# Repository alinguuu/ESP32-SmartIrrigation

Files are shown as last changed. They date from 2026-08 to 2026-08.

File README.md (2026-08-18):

# 🌿 Industrial ESP32 Smart Irrigation & Climate Automation Platform

An industrial-grade, fully integrated smart irrigation and climate automation ecosystem powered by the ESP32. Designed for real-world agricultural, greenhouse, and field applications, this platform unites multi-zone solenoid valve control, digital environmental telemetry, custom 3D CAD/STL hardware enclosures, addressable visual status indicators, and TOTP 2FA security into a unified IoT solution.

<details>
  <summary>🔍 Click to View Full Hardware Wiring Diagram</summary>
  <br>
  <p align="center">
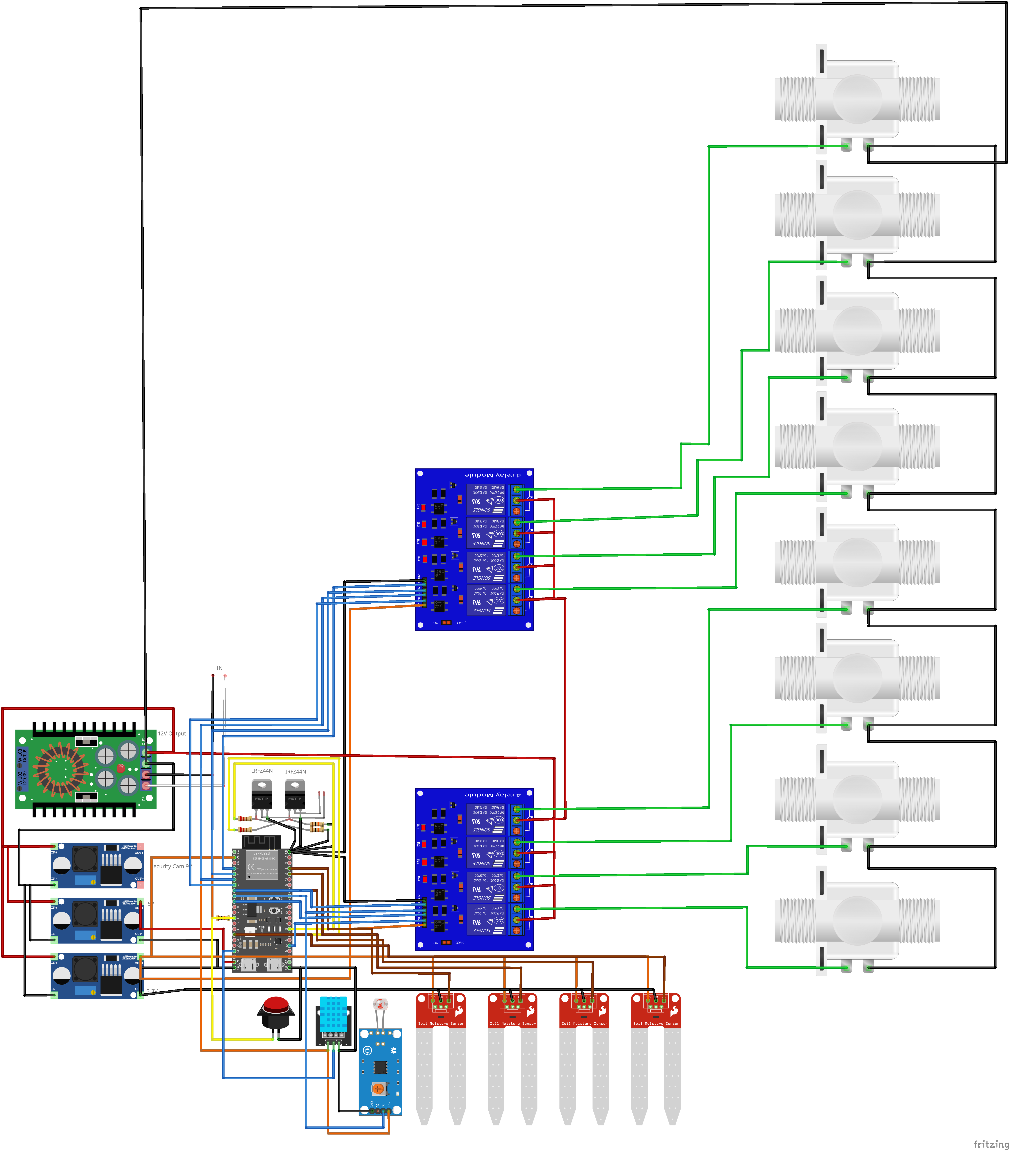
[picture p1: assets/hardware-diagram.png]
Hardware Wiring Diagram
    
  </p>
</details>

---

## 🚀 Overview & System Architecture

Unlike typical hobbyist IoT projects that rely on generic breadboards or basic relay modules, this platform is engineered from the ground up for industrial field reliability, high physical durability, and multi-layered security.

It bridges the gap between low-level hardware control and high-level user accessibility by providing both a responsive Web Control Panel for desktop browsers and a standalone Android application for field operation.

---

## 🌟 Key Features & Capabilities

### 💧 Multi-Zone Solenoid Valve Control
* **8 Independent Relay Channels:** Capable of driving 8 high-power 12V/24V solenoid valves across different irrigation zones (e.g., greenhouses, drip lines, flower beds).
* **Automatic Safety Cutoff Timers:** Features an integrated 30-minute safety timer per relay channel to prevent accidental field flooding or crop damage in the event of network disconnection.

### 📊 Digital Telemetry & Environmental Sensing
* **4-Zone Digital Soil Moisture Monitoring:** Reads digital high/low soil saturation levels to automate watering routines dynamically.
* **Climate Monitoring:** Integrated DHT11 sensor tracks ambient temperature and humidity in real time.
* **Light Intensity Sensing:** Onboard LDR sensor detects sunlight exposure to optimize night/day irrigation scheduling.

### 🔒 Industrial Security (TOTP 2FA)
* **Time-based One-Time Password (2FA):** Implements a Time-based One-Time Password (TOTP) algorithm directly on the ESP32. Sensitive manual overrides, valve toggles, and system settings require valid 2FA authentication via standard mobile authenticator apps (Google Authenticator, Authy).

### 💡 Visual Status Feedback (WLED & Indicators)
* **Addressable WLED Status Lighting:** Utilizes addressable LED strips to provide instant visual diagnostic codes across the enclosure (e.g., active zone indicators, error alerts, standby breathing effects).
* **Enclosure & Panel Lighting:** Auxiliary MOSFET output drivers support high-brightness enclosure LEDs and physical panel status indicators.

---

## 🎨 Custom 3D CAD & Hardware Enclosure Suite

The platform features a complete custom-designed 3D CAD ecosystem stored in the `assets/` directory. All models are optimized for 3D printing (PLA/PETG/TPU) and field deployment:

* **Banana Pi Pro A20 SBC Housing:** Features a hexagonal airflow pattern with active fan mounting to house the central server unit (`cad-bananapi-case-bottom-hex.stl`, `cad-bananapi-case-top-fan.stl`).
* **Soil Sensor Protective Casings:** Weatherproof vertical enclosures with protective top caps designed to shield sensitive electronics from outdoor dirt and moisture (`cad-soil-sensor-casing.stl`, `cad-soil-sensor-cap.stl`).
* **Solenoid Valve Enclosures:** Custom manifold covers equipped with cutouts for status LEDs (`cad-valve-enclosure-main.stl`, `cad-valve-top-cover-led.stl`).
* **Modular Cable Management Boxes:** Junction boxes built for green pluggable terminal blocks to ensure clean wiring and prevent short circuits (`cad-cable-junction-box-large.stl`, `cad-cable-junction-box-small.stl`).
* **Main Panel Chassis:** Heavy-duty internal chassis plate for organized electrical cabinet mounting (`cad-main-mounting-plate.stl`).

---

## 🖥️ User Interfaces & Remote Control

* **Responsive Web Dashboard:** Access real-time sensor graphs, set automated timers, view system logs, and manually trigger valve channels from any desktop or mobile browser.
* **Native Android Application:** Pre-compiled Android APK for quick field control without needing to open a browser.
* **Physical Panel Control:** Includes manual physical button inputs directly on the enclosure for local field operations.

---

## 🛠️ Complete Hardware Wiring & Fritzing Schematic

The hardware layout integrates power regulation, logic isolation, and sensor buses into a clean industrial enclosure:

* **Editable Fritzing Source:** Available at [`assets/hardware-diagram.fzz`](assets/hardware-diagram.fzz).
* **High-Resolution Diagram:** Available at [`assets/hardware-diagram.png`](assets/hardware-diagram.png).

---

## 📖 Complete Technical Setup Guide

For detailed hardware pin mappings, step-by-step firmware compiling, library dependencies, software flashing, and Android APK installation instructions, please refer to our dedicated guide:

➡️ **[View Full Technical Setup & Installation Guide (SETUP.md)](SETUP.md)**

---

> 🇹🇷 **Türkçe Makale & Detaylı İnceleme**  
> Bu projenin Türkçe kurulum rehberine, donanım mimarisine ve saha tecrübelerine [utkudsoz.com.tr](https://utkudsoz.com.tr/esp32-s3-ile-endustriyel-akilli-sulama-ve-iklim-otomasyonu/) üzerinden ulaşabilirsiniz.

---

## 📄 License

Distributed under the MIT License. See `LICENSE` for more information.

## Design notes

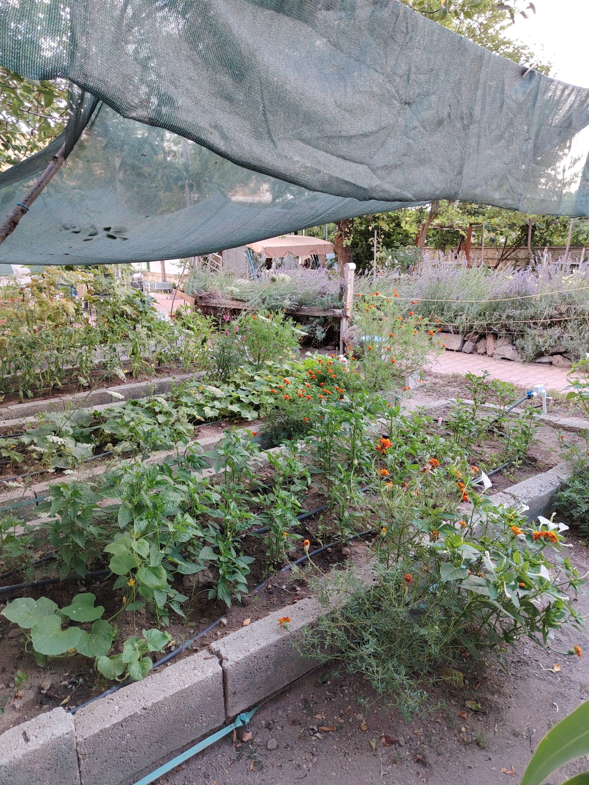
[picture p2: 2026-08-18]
assets/photo-gallery/field-garden-overview.jpeg

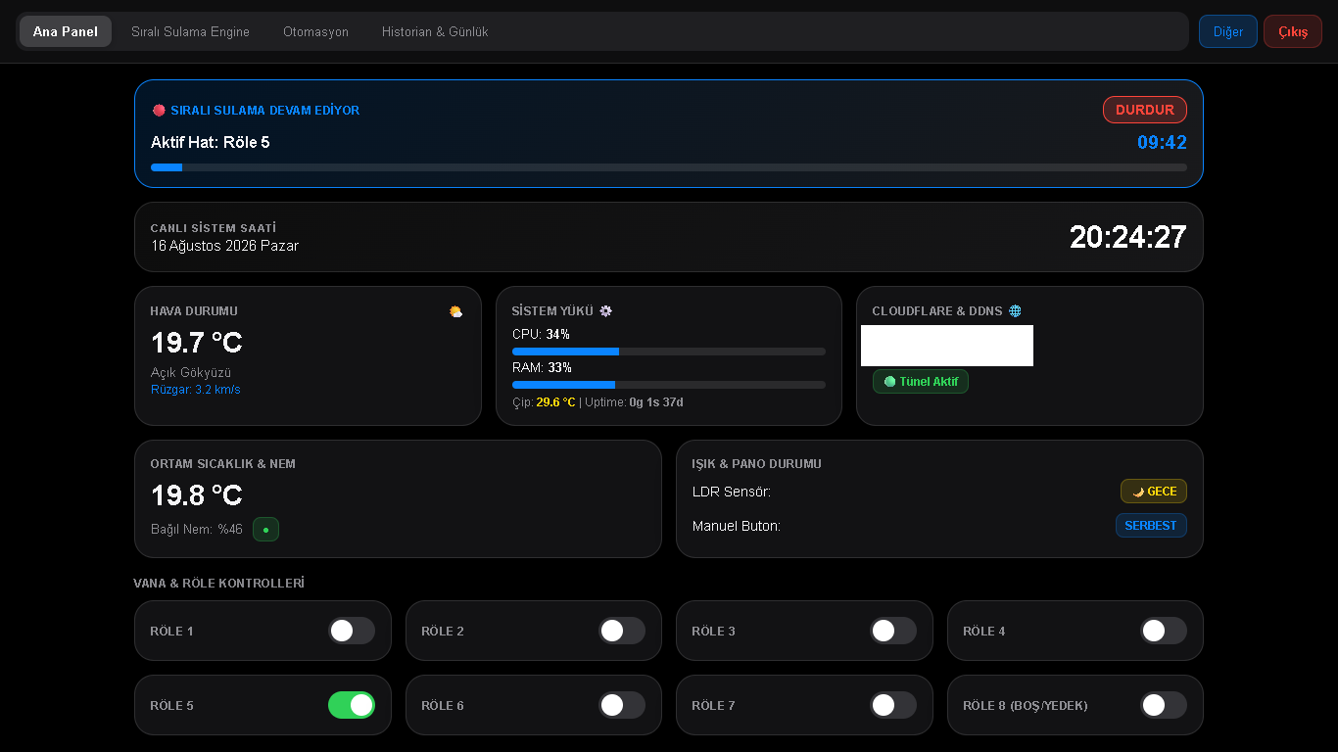
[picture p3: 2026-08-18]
assets/photo-gallery/ui-dashboard-overview.png

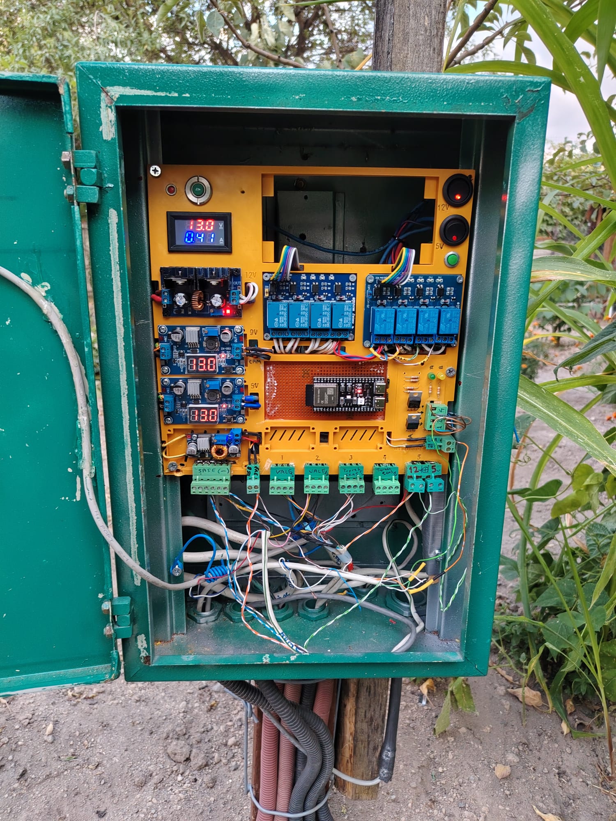
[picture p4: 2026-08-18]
assets/photo-gallery/box-overview.jpeg

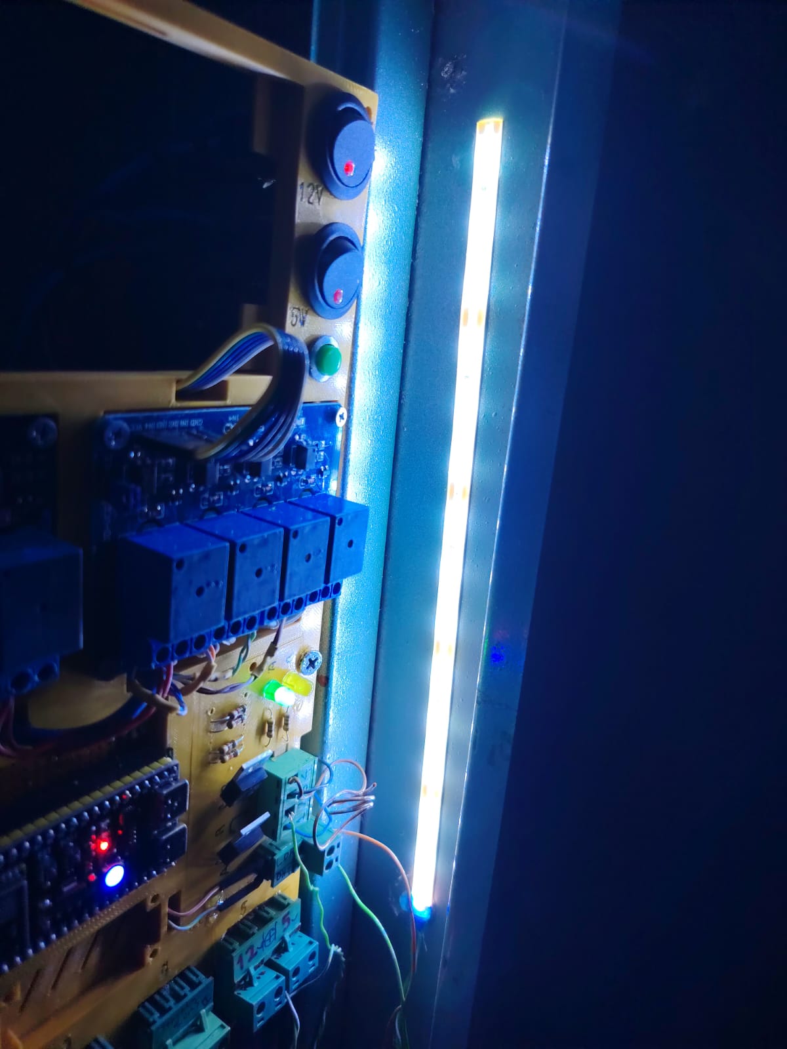
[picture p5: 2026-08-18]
assets/photo-gallery/box-inside-LED.jpeg

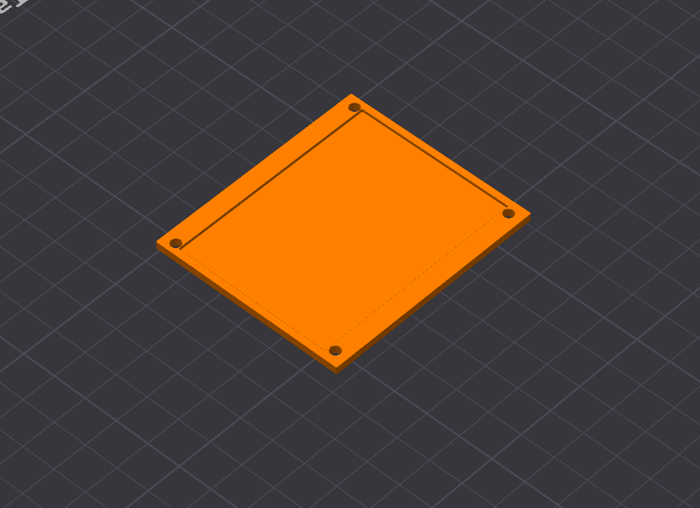
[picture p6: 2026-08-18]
assets/3d-files/cable-box-cover-large.png

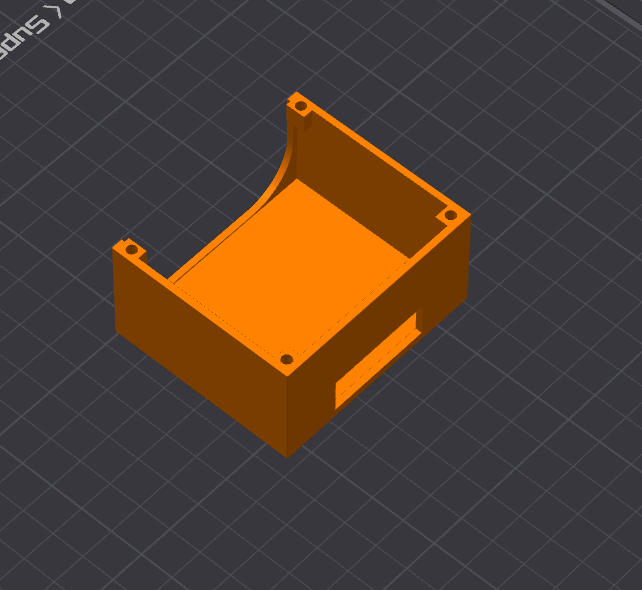
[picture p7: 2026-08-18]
assets/3d-files/cable-junction-box-large.png

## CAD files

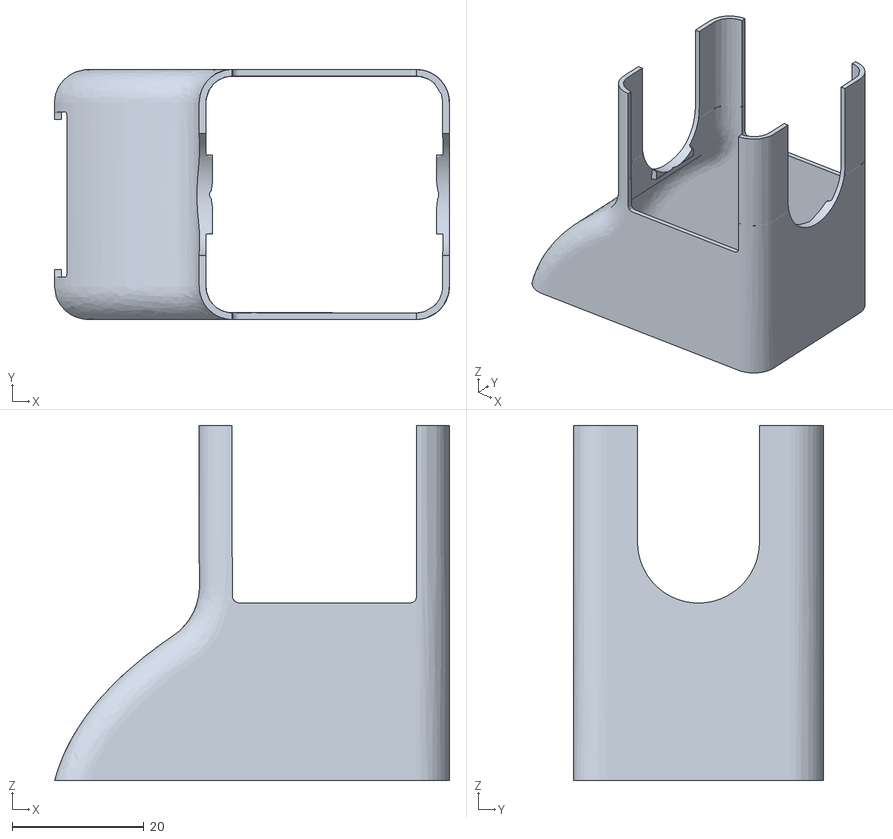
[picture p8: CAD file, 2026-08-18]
assets/3d-files/valve-enclosure-main.stl
60.0 x 38.0 x 54.0

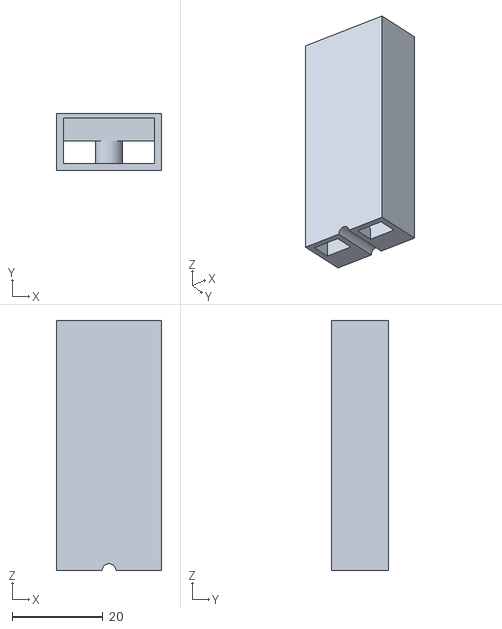
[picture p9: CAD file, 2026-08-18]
assets/3d-files/soil-sensor-casing.stl
23.0 x 12.5 x 55.0

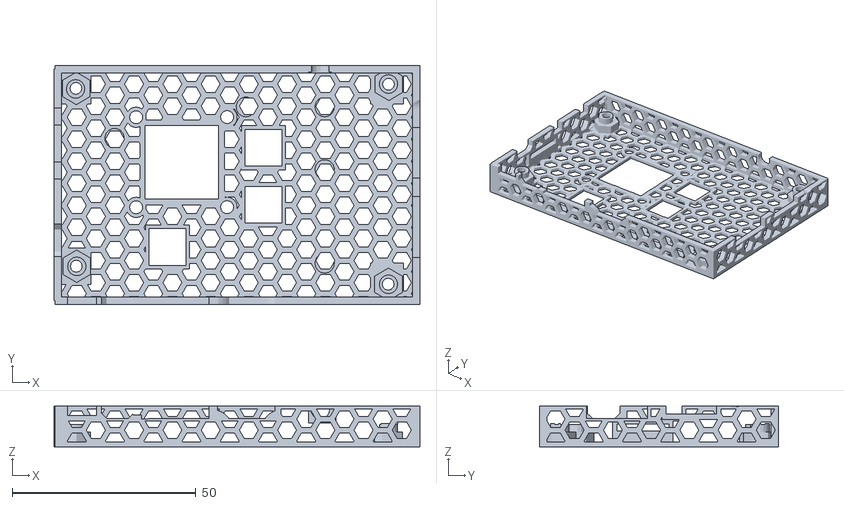
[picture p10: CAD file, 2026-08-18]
assets/3d-files/bananapi-case-bottom-fan.stl
99.6 x 65.1 x 11.0

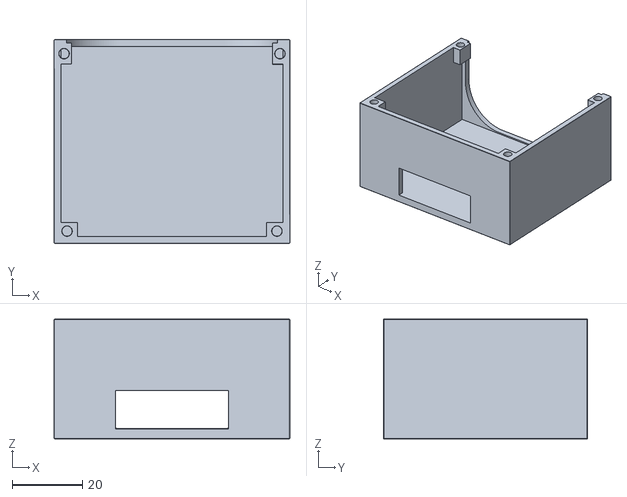
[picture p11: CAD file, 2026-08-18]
assets/3d-files/cable-junction-box-large.stl
67.0 x 58.0 x 34.0

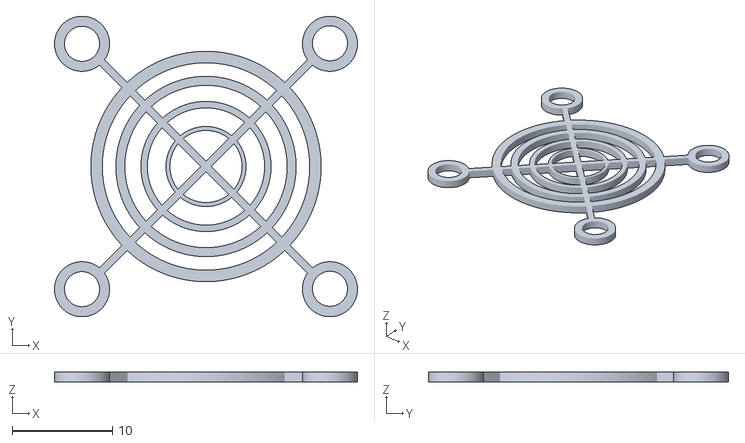
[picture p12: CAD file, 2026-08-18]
assets/3d-files/fan-grille.stl
30.2 x 30.0 x 1.00

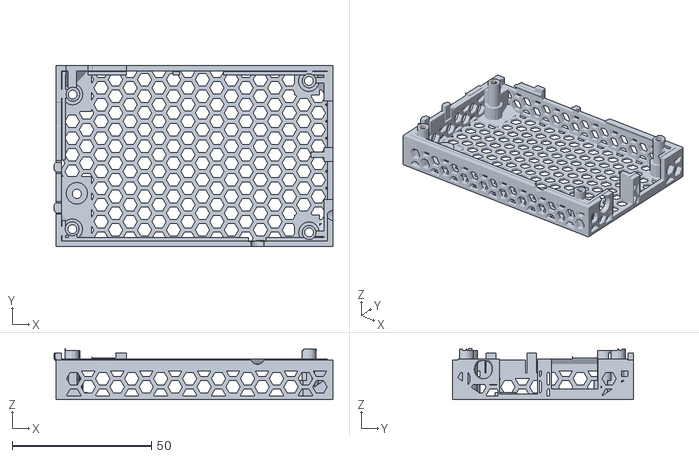
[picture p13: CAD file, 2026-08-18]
assets/3d-files/bananapi-case-top.stl
100.2 x 65.1 x 18.4

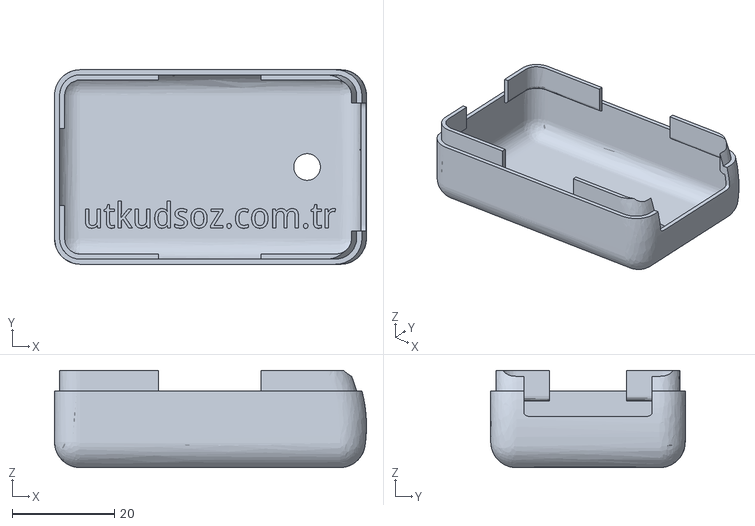
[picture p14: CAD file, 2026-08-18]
assets/3d-files/valve-top-cover-led.stl
60.9 x 38.0 x 19.0

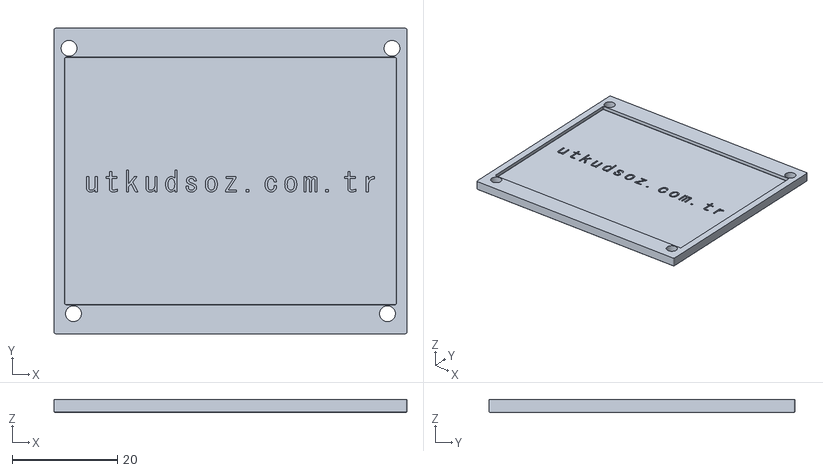
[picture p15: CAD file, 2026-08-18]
assets/3d-files/cable-box-cover-large.stl
67.0 x 58.0 x 2.49

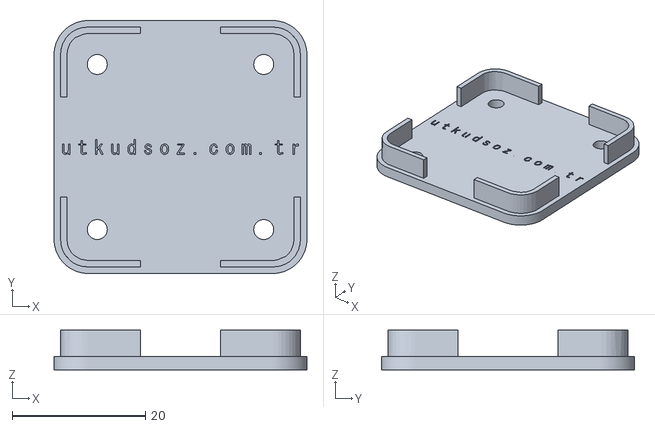
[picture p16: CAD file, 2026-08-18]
assets/3d-files/valve-mount-plate.stl
38.0 x 38.0 x 6.00

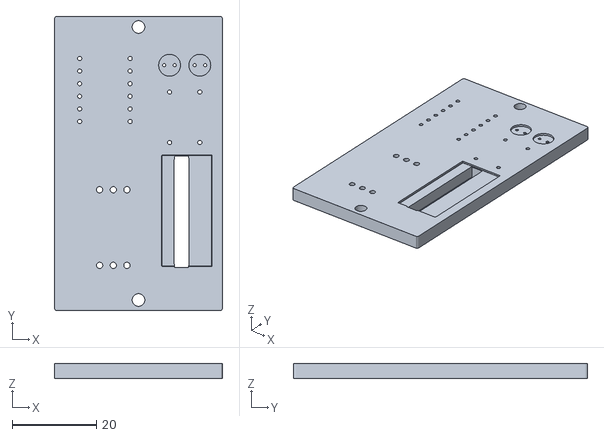
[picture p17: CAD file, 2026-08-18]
assets/3d-files/mosfet-driver-plate.stl
40.0 x 70.0 x 3.50

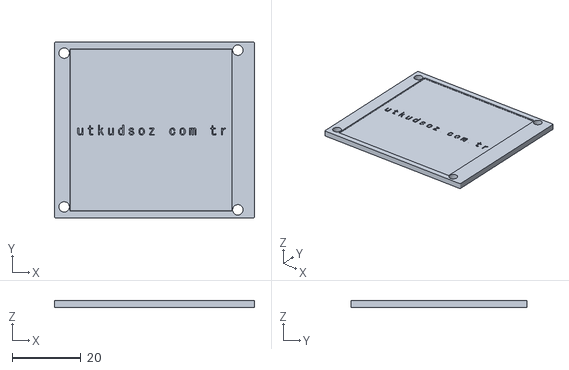
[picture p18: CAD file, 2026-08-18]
assets/3d-files/cable-box-cover-small.stl
58.0 x 51.0 x 2.00

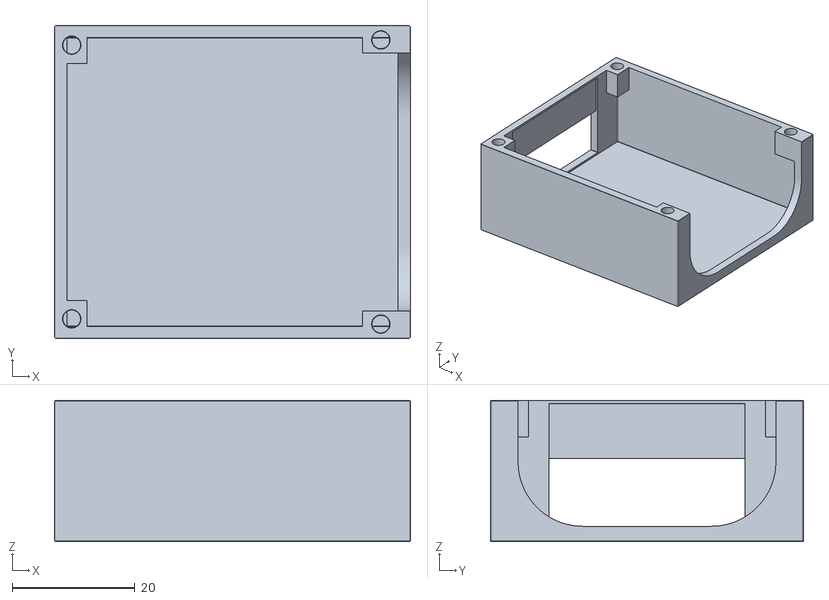
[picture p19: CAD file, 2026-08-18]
assets/3d-files/cable-junction-box-small.stl
58.0 x 51.0 x 23.0

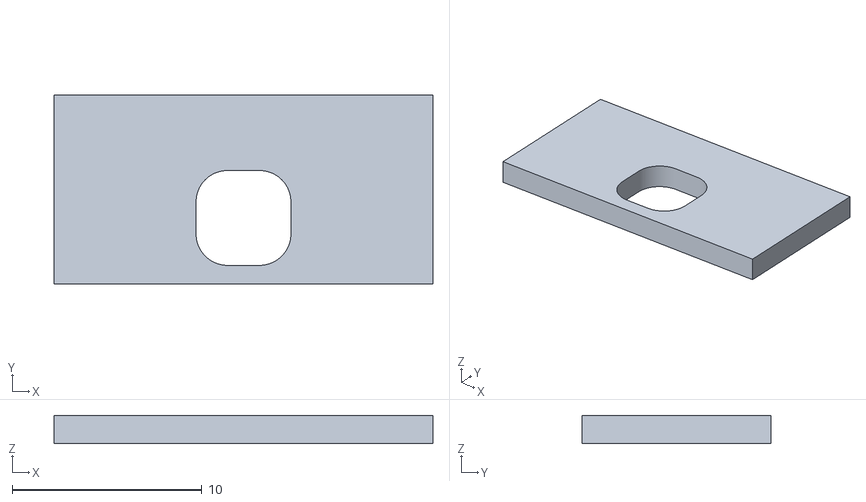
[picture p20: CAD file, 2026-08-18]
assets/3d-files/soil-sensor-cap.stl
20.0 x 10.0 x 1.50

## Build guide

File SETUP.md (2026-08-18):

# 🛠️ Complete Technical Setup & Deployment Guide

This is the comprehensive technical manual for setting up, compiling, configuring, and deploying the **ESP32-S3 Smart Irrigation & Climate Automation Platform**.

---

## 📐 Schematics & Source Links

* **Wiring Diagram:** [`assets/hardware-diagram.png`](https://github.com/alinguuu/ESP32-SmartIrrigation/blob/main/assets/hardware-diagram.png)
* **Fritzing Project:** [`assets/hardware-diagram.fzz`](https://github.com/alinguuu/ESP32-SmartIrrigation/blob/main/assets/hardware-diagram.fzz)
* **Main Firmware (`main.ino`):** [`main.ino`](https://github.com/alinguuu/ESP32-SmartIrrigation/blob/main/main.ino)
* **Web UI Header (`index.h`):** [`index.h`](https://github.com/alinguuu/ESP32-SmartIrrigation/blob/main/index.h)

---

## 📦 Bill of Materials (BOM)

### Controller & Computing
* **ESP32-S3-DevKitC-1-N8R2** (8MB Flash / 2MB PSRAM)
* **Banana Pi Pro A20** (Network server/broker, housed in a custom 3D case)

### Power Management
* **1x XL4016 Buck Converter:** Main 12V DC power rail for solenoid valves.
* **1x XL6009 Buck-Boost:** 9V DC output for auxiliary camera hardware.
* **1x XL6009 Buck-Boost:** 5V DC output for ESP32-S3 board and relay logic.
* **1x XL6009 Buck-Boost:** 3.3V DC output dedicated to sensor logic.

### Actuators & Sensors
* **2x 4-Channel Relay Modules** (8 solenoid valves, switching 12V DC)
* **2x IRFZ44N MOSFETs** (Enclosure LED and secondary high-power outputs)
* **4x Digital Soil Moisture Sensors**
* **1x DHT11 Sensor** (Temperature & Humidity)
* **1x LDR Light Sensor Module** (Digital Output via LM393)
* **1x Physical Panel Pushbutton**
* **1x WS2812B / WLED Strip** (Remote network-connected visual indicator)

---

## 🔌 Pin Mapping Summary

| Module / Function | Pin | ESP32-S3 GPIO | Signal Type |
| :--- | :--- | :--- | :--- |
| **Relay Channels (1-8)** | IN1 - IN8 | `GPIO 4, 5, 6, 7, 15, 16, 17, 21` | Digital Output (5V) |
| **Soil Sensors (1-4)** | DO | `GPIO 1, 2, 10, 40` | Digital Input (3.3V) |
| **DHT11 Sensor** | DATA | `GPIO 13` | Digital Input (3.3V) |
| **LDR Sensor** | DO | `GPIO 39` | Digital Input (3.3V) |
| **Panel Pushbutton** | STATE | `GPIO 3` | Digital Input (Pull-Up) |
| **Enclosure LED MOSFET**| GATE | `GPIO 45` | PWM Output |
| **Auxiliary MOSFET** | GATE | `GPIO 46` | PWM Output |

---

## 💻 Step-by-Step Firmware Setup & Flashing

### Step 1: Environment Preparation
1. Install **VS Code** with the **PlatformIO** extension (recommended) or **Arduino IDE 2.x**.
2. If using Arduino IDE, install the **ESP32 Board Package** via Board Manager (`https://raw.githubusercontent.com/espressif/arduino-esp32/gh-pages/package_esp32_index.json`).
3. Select board target: `ESP32S3 Dev Module`.

### Step 2: Library Dependencies
Ensure the following libraries are installed before compilation:
* `WiFi.h` & `WebServer.h` (ESP32 Core)
* `HTTPClient.h` (WLED API Requests)
* `DHT sensor library` by Adafruit
* `Preferences.h` & `LittleFS.h` (NVS Storage)
* `mbedtls/sha1.h` (Hardware TOTP Cryptography)

### Step 3: Understanding `index.h`
The entire web interface (HTML, CSS, JavaScript) is placed inside `index.h` using standard C++ `PROGMEM` syntax:
* **Memory Optimization:** Stored directly in ESP32-S3 Flash memory, keeping RAM free for real-time sensor cycles.
* **Modularity:** Keeps core logic in `main.ino` clean and separate from web design code.

### Step 4: Configuring Parameters & Flashing
1. Open `main.ino` and update Wi-Fi credentials (`ssid`, `password`).
2. Set your custom **TOTP Secret Key** (Base32 string).
3. Connect the ESP32-S3 via USB-C (ensure correct COM port selected).
4. Set partition scheme to **8MB with Spiffs/LittleFS** if prompted.
5. Click **Upload / Flash** and monitor output via Serial Monitor at **115200 baud**.

---

## 🔒 TOTP 2FA Setup

1. Locate the Base32 Secret Key defined in `main.ino`.
2. Open your 2FA app (**Google Authenticator**, **Authy**, or **1Password**).
3. Choose **"Enter a setup key"** / **"Manual entry"** and paste the key.
4. Name the entry (e.g., *Irrigation System*).
5. Any manual command sent via the Web UI or Mobile App will require the active 6-digit TOTP code generated by your app.

---

## 📲 Mobile App (APK) Setup & Domain Editing

The pre-compiled Android APK targets the default domain: `sulama.utkudsoz.com.tr`.

If you are using a self-hosted server or direct IP, update the APK using **APK Editor**:

1. Download **APK Editor** (Android) or **APK Easy Tool** (Windows).
2. Load the project's APK file.
3. Choose **Full Edit** / **Common Edit**.
4. Search for `sulama.utkudsoz.com.tr` in `assets/` or `res/values/strings.xml`.
5. Replace it with your custom IP or domain (e.g., `192.168.1.100`).
6. Click **Build**, sign the application with a test key, and install it on your smartphone.

---

## 🖨️ 3D Enclosure Assembly & Field Deployment

### Printing Guidelines
* **Material:** PETG or ASA (UV and weather resistant for outdoor environments).
* **Layer Height:** `0.2mm`or `0.12mm`| **Infill:** `20%-30% Gyroid`.

### Assembly Steps
1. **SBC Housing:** Mount Banana Pi Pro A20 in `bananapi-case-bottom-fan.stl` and secure a 5V fan on `bananapi-case-top.stl`.
2. **Soil Probe Protection:** Insert soil probes into `soil-sensor-casing.stl` and apply silicone sealant around `soil-sensor-cap.stl`.
3. **Cable Management:** Route 12V valve wiring through `cable-junction-box-large.stl` using green terminal blocks to prevent short circuits.
4. **Main Chassis:** Secure relay modules and power converters to `main-mounting-plate.stl` inside the main electrical box.

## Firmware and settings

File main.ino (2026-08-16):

/**
 * Created by Utku Doğrusöz
 * ESP32-SmartIrrigation System
 * Firmware for automated multi-zone irrigation management via web interface.
 */

#include <WiFi.h>
#include <WebServer.h>
#include <HTTPClient.h>
#include <DHT.h>
#include <time.h>
#include <Preferences.h>
#include <LittleFS.h>
#include "esp_system.h"
#include "mbedtls/sha1.h"
#include "index.h"

// --- Non-Volatile Memory Storage ---
Preferences preferences;

// --- Authentication Credentials & TOTP Secret (Change Before Deployment) ---
const char* AUTH_USER = "YOUR_USER";
const char* AUTH_PASS = "YOUR_PASSWORD";
const char* TOTP_SECRET = "YOUR_SECRET"; // Base32 TOTP Secret Key

// --- Wi-Fi & Static IP Configuration ---
const char* ssid = "YOUR_WIFI_SSID";
const char* password = "YOUR_WIFI_PASSWORD";

IPAddress local_IP(192, 168, 1, 100);
IPAddress gateway(192, 168, 1, 1);
IPAddress subnet(255, 255, 255, 0);
IPAddress primaryDNS(192, 168, 1, 1);

// --- WLED Remote Device Configuration ---
String wledIP = "YOUR_WLED_IP"; 
bool lastWledState = false;
String lastWledColor = "#ffb464";

bool wledNightAutoEnabled = true;
int wledNightBri = 100;         
bool wledNightStateActive = false;

// --- Hardware Pin Configurations ---
#define DHTPIN 13
#define DHTTYPE DHT11
DHT dht(DHTPIN, DHTTYPE);

// Relay output pins for 8 channels
const int relayPins[8] = {4, 5, 6, 7, 15, 16, 17, 21};
bool relayStates[8] = {false, false, false, false, false, false, false, false};

// Automatic safety cutoff timers for relays
unsigned long relayAutoOffTimer[8] = {0};
const unsigned long MANUAL_TIMEOUT_MS = 30 * 60 * 1000; // 30-minute safety shutoff

// Digital Soil Moisture Sensors (Digital High/Low)
const int moisturePins[4] = {1, 2, 10, 40}; 
const int ldrPin = 39;
const int panelButtonPin = 3;

const int enclosureLedPin = 45;
const int secondaryFetPin = 46;

bool enclosureLedState = false;
bool secondaryFetState = false;

// --- Sequential Irrigation Logic Variables (Relays 1 to 7) ---
bool seqActive = false;
int seqCurrentRelayIndex = 0; 
unsigned long seqStartTime = 0;
unsigned long seqDurationMs = 0;

int relayCustomMinutes[7] = {10, 10, 10, 10, 10, 10, 10};
bool relaySkipFlags[7] = {false, false, false, false, false, false, false};
float currentMultiplier = 1.0; 
bool seqDualMode = false;

// --- NTP Time Sync Settings ---
const char* ntpServer = "pool.ntp.org";
const long gmtOffset_sec = 3 * 3600; // Timezone Offset (e.g., UTC+3)
const int daylightOffset_sec = 0;

WebServer server(80);

// --- Dynamic Automation Rule Structure ---
struct AutoRule {
  int id;
  String type;   // "time", "nem_kuru", "temp_high", "ldr_night"
  String target; // "0".."6", "seq_all"
  String val;    // Parameter value (e.g., "14:30" or threshold)
  String action; // "ON", "OFF"
};

#define MAX_RULES 10
AutoRule rules[MAX_RULES];
int ruleCount = 0;
int nextRuleId = 1;

// --- Circular Buffer System Logs ---
#define MAX_LOGS 40
String systemLogs[MAX_LOGS];
int logCount = 0;

String publicIP = "0.0.0.0"; 

// --- TOTP / Google Authenticator Helper Functions ---
int base32Decode(const char* base32, uint8_t* output) {
  int buffer = 0, bitsLeft = 0, count = 0;
  for (const char* ptr = base32; *ptr; ++ptr) {
    char ch = *ptr;
    if (ch == ' ' || ch == '\t' || ch == '\r' || ch == '\n' || ch == '=') continue;
    int val = 0;
    if (ch >= 'A' && ch <= 'Z') val = ch - 'A';
    else if (ch >= 'a' && ch <= 'z') val = ch - 'a';
    else if (ch >= '2' && ch <= '7') val = ch - '2' + 26;
    else return -1;
    buffer = (buffer << 5) | val;
    bitsLeft += 5;
    if (bitsLeft >= 8) {
      output[count++] = (buffer >> (bitsLeft - 8)) & 0xFF;
      bitsLeft -= 8;
    }
  }
  return count;
}

uint32_t generateTOTP(const char* secretBase32, uint64_t timeStep) {
  uint8_t key[32];
  int keyLen = base32Decode(secretBase32, key);
  if (keyLen <= 0) return 0;

  uint8_t msg[8];
  for (int i = 7; i >= 0; i--) {
    msg[i] = timeStep & 0xFF;
    timeStep >>= 8;
  }

  uint8_t k_ipad[64], k_opad[64];
  memset(k_ipad, 0x36, 64);
  memset(k_opad, 0x5c, 64);
  for (int i = 0; i < keyLen; i++) {
    k_ipad[i] ^= key[i];
    k_opad[i] ^= key[i];
  }

  uint8_t shaInner[20];
  mbedtls_sha1_context ctx;
  mbedtls_sha1_init(&ctx);
  mbedtls_sha1_starts(&ctx);
  mbedtls_sha1_update(&ctx, k_ipad, 64);
  mbedtls_sha1_update(&ctx, msg, 8);
  mbedtls_sha1_finish(&ctx, shaInner);

  uint8_t hmac[20];
  mbedtls_sha1_starts(&ctx);
  mbedtls_sha1_update(&ctx, k_opad, 64);
  mbedtls_sha1_update(&ctx, shaInner, 20);
  mbedtls_sha1_finish(&ctx, hmac);
  mbedtls_sha1_free(&ctx);

  int offset = hmac[19] & 0x0F;
  uint32_t binary = ((hmac[offset] & 0x7F) << 24) |
                    ((hmac[offset + 1] & 0xFF) << 16) |
                    ((hmac[offset + 2] & 0xFF) << 8) |
                    (hmac[offset + 3] & 0xFF);

  return binary % 1000000;
}

bool verifyTOTP(String userCode) {
  time_t now;
  time(&now);
  if (now < 1700000000) return true; // Bypass verification if NTP time sync is uninitialized

  uint64_t timeStep = now / 30;
  for (int i = -1; i <= 1; i++) {
    uint32_t code = generateTOTP(TOTP_SECRET, timeStep + i);
    char codeBuf[7];
    sprintf(codeBuf, "%06u", code);
    if (userCode == String(codeBuf)) return true;
  }
  return false;
}

String getFormattedTime() {
  struct tm timeinfo;
  if (!getLocalTime(&timeinfo)) return "00:00:00";
  char timeStringBuff[10];
  strftime(timeStringBuff, sizeof(timeStringBuff), "%H:%M:%S", &timeinfo);
  return String(timeStringBuff);
}

void addLog(String message) {
  String currentTime = getFormattedTime();
  String entry = "[" + currentTime + "] " + message;
  
  if (logCount < MAX_LOGS) {
    systemLogs[logCount] = entry;
    logCount++;
  } else {
    for (int i = 0; i < MAX_LOGS - 1; i++) {
      systemLogs[i] = systemLogs[i + 1];
    }
    systemLogs[MAX_LOGS - 1] = entry;
  }
  Serial.println(entry);
}

String getSystemUptime() {
  unsigned long sec = millis() / 1000;
  unsigned long min = sec / 60;
  unsigned long hr = min / 60;
  unsigned long day = hr / 24;
  sec %= 60; min %= 60; hr %= 24;
  return String(day) + "d " + String(hr) + "h " + String(min) + "m";
}

float getChipTemperature() {
  float temp = temperatureRead();
  return (isnan(temp) || temp == 0.0) ? 42.5 : temp;
}

int getCPUUsage() { return random(12, 35); }

void loadSettingsFromEEPROM() {
  preferences.begin("irrigation", true);
  for (int i = 0; i < 7; i++) {
    String key = "r_time_" + String(i);
    relayCustomMinutes[i] = preferences.getInt(key.c_str(), 10);
  }
  wledNightAutoEnabled = preferences.getBool("wn_auto", true);
  wledNightBri         = preferences.getInt("wn_bri", 100);
  preferences.end();
  addLog("Settings loaded from EEPROM.");
}

void saveRelayTimesToEEPROM() {
  preferences.begin("irrigation", false);
  for (int i = 0; i < 7; i++) {
    String key = "r_time_" + String(i);
    preferences.putInt(key.c_str(), relayCustomMinutes[i]);
  }
  preferences.end();
  addLog("Relay durations saved to EEPROM.");
}

void saveWLEDConfigToEEPROM() {
  preferences.begin("irrigation", false);
  preferences.putBool("wn_auto", wledNightAutoEnabled);
  preferences.putInt("wn_bri", wledNightBri);
  preferences.end();
  addLog("WLED automation settings saved.");
}

void sendWLEDCommand(String jsonBody) {
  if (WiFi.status() == WL_CONNECTED) {
    HTTPClient http;
    http.begin("http://" + wledIP + "/json/state");
    http.setTimeout(300);
    http.addHeader("Content-Type", "application/json");
    http.POST(jsonBody);
    http.end();
  }
}

String getWLEDStateJSON() {
  if (WiFi.status() != WL_CONNECTED) {
    return "{\"state\":" + String(lastWledState ? "true" : "false") + ",\"color\":\"" + lastWledColor + "\",\"bri\":128,\"fx\":0}";
  }
  HTTPClient http;
  http.begin("http://" + wledIP + "/json/state");
  http.setTimeout(250);
  int httpCode = http.GET();
  int bri = 128, fx = 0;
  
  if (httpCode == HTTP_CODE_OK) {
    String payload = http.getString();
    int onIdx = payload.indexOf("\"on\":");
    if (onIdx != -1) lastWledState = (payload.substring(onIdx + 5, onIdx + 11).indexOf("true") != -1);
    int briIdx = payload.indexOf("\"bri\":");
    if (briIdx != -1) bri = payload.substring(briIdx + 6).toInt();
    int fxIdx = payload.indexOf("\"fx\":");
    if (fxIdx != -1) fx = payload.substring(fxIdx + 5).toInt();
  }
  http.end();
  
  return "{\"state\":" + String(lastWledState ? "true" : "false") + ",\"color\":\"" + lastWledColor + "\",\"bri\":" + String(bri) + ",\"fx\":" + String(fx) + "}";
}

void handleWLEDNightAutomation() {
  if (!wledNightAutoEnabled || seqActive) return;

  static unsigned long lastCheck = 0;
  if (millis() - lastCheck < 3000) return; 
  lastCheck = millis();

  bool isNightByLDR = (digitalRead(ldrPin) == HIGH); 

  if (isNightByLDR && !wledNightStateActive) {
    wledNightStateActive = true;
    lastWledState = true;
    String payload = "{\"on\":true,\"bri\":" + String(wledNightBri) + ",\"seg\":[{\"fx\":0,\"col\":[[255,180,100]]}]}";
    sendWLEDCommand(payload);
    addLog("AUTOMATION: Darkness detected -> WLED Warm White ON 💡");
  } 
  else if (!isNightByLDR && wledNightStateActive) {
    wledNightStateActive = false;
    lastWledState = false;
    sendWLEDCommand("{\"on\":false}");
    addLog("AUTOMATION: Daylight detected -> WLED OFF ☀️");
  }
}

// --- SEQUENTIAL IRRIGATION (RELAYS 1-7) & WLED WATER EFFECT ---
void stopSequentialIrrigation() {
  seqActive = false;
  for (int i = 0; i < 7; i++) {
    relayStates[i] = false;
    digitalWrite(relayPins[i], HIGH);
    relayAutoOffTimer[i] = 0;
  }
  sendWLEDCommand("{\"on\":false}");
  addLog("Sequential Irrigation Stopped. WLED OFF.");
}

void startNextSeqRelay() {
  for (int i = 0; i < 7; i++) {
    relayStates[i] = false;
    digitalWrite(relayPins[i], HIGH);
    relayAutoOffTimer[i] = 0;
  }

  while (seqCurrentRelayIndex < 7 && relaySkipFlags[seqCurrentRelayIndex]) {
    addLog("Sequential Step: Relay " + String(seqCurrentRelayIndex + 1) + " SKIPPED");
    seqCurrentRelayIndex++;
  }

  if (seqCurrentRelayIndex >= 7) {
    stopSequentialIrrigation();
    return;
  }

  int rIndex = seqCurrentRelayIndex;
  
  relayStates[rIndex] = true;
  digitalWrite(relayPins[rIndex], LOW); // Active Low Relays

  String stepLog = "Sequential Step: Relay " + String(rIndex + 1);

  if (seqDualMode && (rIndex + 1 < 7) && !relaySkipFlags[rIndex + 1]) {
    relayStates[rIndex + 1] = true;
    digitalWrite(relayPins[rIndex + 1], LOW);
    stepLog += " & Relay " + String(rIndex + 2) + " (Dual Mode)";
  }

  float targetMin = relayCustomMinutes[rIndex] * currentMultiplier;
  seqDurationMs = (unsigned long)(targetMin * 60.0 * 1000.0);
  seqStartTime = millis();

  // WLED Water Effect (Pacific Wave - FX: 101)
  sendWLEDCommand("{\"on\":true,\"bri\":200,\"seg\":[{\"fx\":101,\"col\":[[0,150,255]]}]}");

  stepLog += " (" + String(targetMin, 1) + " min)";
  addLog(stepLog);
}

void handleSequentialLogic() {
  if (!seqActive) return;
  if (millis() - seqStartTime >= seqDurationMs) {
    seqCurrentRelayIndex += (seqDualMode ? 2 : 1);
    startNextSeqRelay();
  }
}

void handleSafetyTimeouts() {
  if (seqActive) return;
  unsigned long now = millis();
  for (int i = 0; i < 8; i++) {
    if (relayStates[i] && relayAutoOffTimer[i] > 0) {
      if (now - relayAutoOffTimer[i] >= MANUAL_TIMEOUT_MS) {
        relayStates[i] = false;
        digitalWrite(relayPins[i], HIGH);
        relayAutoOffTimer[i] = 0;
        addLog("SAFETY: Relay " + String(i + 1) + " timed out & switched OFF!");
      }
    }
  }
}

// --- AUTOMATION ENGINE EVALUATOR ---
void handleAutomationRulesEngine() {
  static unsigned long lastAutoCheck = 0;
  if (millis() - lastAutoCheck < 5000) return; 
  lastAutoCheck = millis();

  struct tm timeinfo;
  bool timeValid = getLocalTime(&timeinfo);
  char currentHM[6] = "";
  if (timeValid) {
    strftime(currentHM, sizeof(currentHM), "%H:%M", &timeinfo);
  }

  for (int i = 0; i < ruleCount; i++) {
    bool trigger = false;

    if (rules[i].type == "time" && timeValid) {
      if (String(currentHM) == rules[i].val) trigger = true;
    }
    else if (rules[i].type == "nem_kuru") {
      bool isDry = false;
      for (int k = 0; k < 4; k++) {
        if (digitalRead(moisturePins[k]) == HIGH) { isDry = true; break; }
      }
      if (isDry) trigger = true;
    }
    else if (rules[i].type == "temp_high") {
      float t = dht.readTemperature();
      if (!isnan(t) && t > rules[i].val.toFloat()) trigger = true;
    }
    else if (rules[i].type == "ldr_night") {
      if (digitalRead(ldrPin) == HIGH) trigger = true;
    }

    if (trigger) {
      if (rules[i].target == "seq_all") {
        if (!seqActive && rules[i].action == "ON") {
          addLog("RULE TRIGGERED: Starting Sequential Irrigation");
          seqActive = true;
          seqCurrentRelayIndex = 0;
          startNextSeqRelay();
        }
      } else {
        int rId = rules[i].target.toInt();
        if (rId >= 0 && rId < 8) {
          bool desiredState = (rules[i].action == "ON");
          if (relayStates[rId] != desiredState) {
            relayStates[rId] = desiredState;
            digitalWrite(relayPins[rId], desiredState ? LOW : HIGH);
            relayAutoOffTimer[rId] = desiredState ? millis() : 0;
            addLog("RULE TRIGGERED: Relay " + String(rId + 1) + (desiredState ? " TURNED ON" : " TURNED OFF"));
          }
        }
      }
    }
  }
}

// --- APK STREAM HANDLER ---
void handleDownloadAPK() {
  if (!LittleFS.exists("/app-release.apk")) {
    server.send(404, "text/plain", "APK File Not Found in Flash Storage!");
    return;
  }
  
  File apkFile = LittleFS.open("/app-release.apk", "r");
  if (!apkFile) {
    server.send(500, "text/plain", "Failed to open APK file!");
    return;
  }

  addLog("APK Download Initiated.");
  server.streamFile(apkFile, "application/vnd.android.package-archive");
  apkFile.close();
}

// --- HTTP SERVER ENDPOINTS ---
void handleRoot() { server.send(200, "text/html", MAIN_page); }

void handleLogin() {
  String u = server.arg("u");
  String p = server.arg("p");
  String code = server.arg("code");

  if (u == AUTH_USER && p == AUTH_PASS && verifyTOTP(code)) {
    addLog("LOGIN SUCCESS: " + u + " (2FA Verified)");
    server.send(200, "application/json", "{\"status\":\"OK\"}");
  } else {
    addLog("LOGIN FAILED for user: " + u);
    server.send(401, "application/json", "{\"status\":\"FAIL\"}");
  }
}

void handleGet2FAKey() {
  server.send(200, "application/json", "{\"secret\":\"" + String(TOTP_SECRET) + "\"}");
}

void handleStatus() {
  float h = dht.readHumidity();
  float t = dht.readTemperature();

  uint32_t freeHeap = ESP.getFreeHeap();
  uint32_t totalHeap = ESP.getHeapSize();
  int heapUsagePercent = 100 - ((freeHeap * 100) / totalHeap);

  uint32_t flashSize = ESP.getFlashChipSize();
  uint32_t sketchSize = ESP.getSketchSize();
  int romUsagePercent = (sketchSize * 100) / flashSize;

  String json = "{";
  json += "\"temp\":" + String(isnan(t) ? 0.0 : t, 1) + ",";
  json += "\"hum\":" + String(isnan(h) ? 0.0 : h, 1) + ",";
  
  json += "\"relays\":[";
  for (int i = 0; i < 8; i++) {
    json += relayStates[i] ? "true" : "false";
    if (i < 7) json += ",";
  }
  json += "],";

  json += "\"nem\":[";
  for (int i = 0; i < 4; i++) {
    json += (digitalRead(moisturePins[i]) == LOW) ? "true" : "false";
    if (i < 3) json += ",";
  }
  json += "],";

  json += "\"ldr\":" + String(digitalRead(ldrPin) == HIGH ? "true" : "false") + ",";
  json += "\"pano_btn\":" + String(digitalRead(panelButtonPin) == LOW ? "true" : "false") + ",";
  json += "\"pano_led\":" + String(enclosureLedState ? "true" : "false") + ",";
  json += "\"ikinci_fet\":" + String(secondaryFetState ? "true" : "false") + ",";
  
  json += "\"sys_temp\":" + String(getChipTemperature(), 1) + ",";
  json += "\"sys_cpu\":" + String(getCPUUsage()) + ",";
  json += "\"sys_heap\":" + String(heapUsagePercent) + ",";
  json += "\"sys_rom\":" + String(romUsagePercent) + ",";
  json += "\"sys_uptime\":\"" + getSystemUptime() + "\",";
  json += "\"ddns_ip\":\"" + publicIP + "\",";

  json += "\"seq_active\":" + String(seqActive ? "true" : "false") + ",";
  json += "\"seq_relay\":" + String(seqCurrentRelayIndex) + ",";
  json += "\"seq_dual\":" + String(seqDualMode ? "true" : "false") + ",";
  
  unsigned long elapsed = seqActive ? (millis() - seqStartTime) : 0;
  unsigned long remainMs = (seqActive && seqDurationMs > elapsed) ? (seqDurationMs - elapsed) : 0;
  json += "\"seq_remain_sec\":" + String(remainMs / 1000) + ",";
  json += "\"seq_total_sec\":" + String(seqDurationMs / 1000) + ",";

  json += "\"relay_times\":[";
  for (int i = 0; i < 7; i++) {
    json += String(relayCustomMinutes[i]);
    if (i < 6) json += ",";
  }
  json += "],";

  json += "\"wled\":" + getWLEDStateJSON();
  json += "}";
  
  server.send(200, "application/json", json);
}

void handleRelayToggle() {
  if (server.hasArg("id")) {
    int id = server.arg("id").toInt();
    if (id >= 0 && id < 8) {
      if (seqActive && id < 7) stopSequentialIrrigation();

      relayStates[id] = !relayStates[id];
      digitalWrite(relayPins[id], relayStates[id] ? LOW : HIGH);
      
      relayAutoOffTimer[id] = relayStates[id] ? millis() : 0;
      addLog("Relay " + String(id + 1) + (relayStates[id] ? " TURNED ON" : " TURNED OFF"));
      server.send(200, "text/plain", "OK");
      return;
    }
  }
  server.send(400, "text/plain", "Invalid Parameter");
}

void handleStartSequence() {
  if (server.hasArg("mult")) currentMultiplier = server.arg("mult").toFloat();
  if (server.hasArg("dual")) seqDualMode = (server.arg("dual") == "true");

  if (server.hasArg("skips")) {
    String skipStr = server.arg("skips");
    int idx = 0, lastComma = -1;
    for (int i = 0; i <= skipStr.length(); i++) {
      if (i == skipStr.length() || skipStr.charAt(i) == ',') {
        if (idx < 7) {
          relaySkipFlags[idx] = (skipStr.substring(lastComma + 1, i) == "1");
          idx++;
        }
        lastComma = i;
      }
    }
  }

  seqActive = true;
  seqCurrentRelayIndex = 0;
  startNextSeqRelay();
  server.send(200, "text/plain", "OK");
}

void handleStopSequence() {
  stopSequentialIrrigation();
  server.send(200, "text/plain", "OK");
}

void handleSetRelayTimes() {
  if (server.hasArg("times")) {
    String timesStr = server.arg("times");
    int idx = 0, lastComma = -1;
    for (int i = 0; i <= timesStr.length(); i++) {
      if (i == timesStr.length() || timesStr.charAt(i) == ',') {
        if (idx < 7) {
          relayCustomMinutes[idx] = timesStr.substring(lastComma + 1, i).toInt();
          idx++;
        }
        lastComma = i;
      }
    }
    saveRelayTimesToEEPROM();
    server.send(200, "text/plain", "OK");
    return;
  }
  server.send(400, "text/plain", "Missing Data");
}

void handleEnclosureLedToggle() {
  enclosureLedState = !enclosureLedState;
  digitalWrite(enclosureLedPin, enclosureLedState ? HIGH : LOW);
  server.send(200, "text/plain", "OK");
}

void handleSecondaryFetToggle() {
  secondaryFetState = !secondaryFetState;
  digitalWrite(secondaryFetPin, secondaryFetState ? HIGH : LOW);
  server.send(200, "text/plain", "OK");
}

void handleWLEDToggle() {
  if (server.hasArg("state")) {
    bool state = (server.arg("state") == "true");
    lastWledState = state;
    sendWLEDCommand("{\"on\":" + String(state ? "true" : "false") + "}");
    server.send(200, "text/plain", "OK");
    return;
  }
  server.send(400, "text/plain", "Error");
}

void handleWLEDBrightness() {
  if (server.hasArg("bri")) {
    sendWLEDCommand("{\"bri\":" + String(server.arg("bri").toInt()) + "}");
    server.send(200, "text/plain", "OK");
    return;
  }
  server.send(400, "text/plain", "Error");
}

void handleWLEDEffect() {
  if (server.hasArg("fx")) {
    sendWLEDCommand("{\"seg\":[{\"fx\":" + String(server.arg("fx").toInt()) + "}]}");
    server.send(200, "text/plain", "OK");
    return;
  }
  server.send(400, "text/plain", "Error");
}

void handleWLEDColor() {
  if (server.hasArg("hex")) {
    String hex = server.arg("hex");
    if (hex.startsWith("#")) hex = hex.substring(1);
    long number = strtol(hex.c_str(), NULL, 16);
    int r = number >> 16, g = (number >> 8) & 0xFF, b = number & 0xFF;
    sendWLEDCommand("{\"on\":true,\"seg\":[{\"col\":[[" + String(r) + "," + String(g) + "," + String(b) + "]]}]}");
    server.send(200, "text/plain", "OK");
    return;
  }
  server.send(400, "text/plain", "Error");
}

void handleGetWLEDConfig() {
  String json = "{\"auto\":" + String(wledNightAutoEnabled ? "true" : "false") + ",\"bri\":" + String(wledNightBri) + "}";
  server.send(200, "application/json", json);
}

void handleSetWLEDConfig() {
  if (server.hasArg("auto"))  wledNightAutoEnabled = (server.arg("auto") == "true");
  if (server.hasArg("bri"))   wledNightBri         = server.arg("bri").toInt();

  saveWLEDConfigToEEPROM();
  server.send(200, "text/plain", "OK");
}

void handleGetRules() {
  String json = "[";
  for (int i = 0; i < ruleCount; i++) {
    json += "{\"id\":" + String(rules[i].id) + ",";
    json += "\"type\":\"" + rules[i].type + "\",";
    json += "\"target\":\"" + rules[i].target + "\",";
    json += "\"val\":\"" + rules[i].val + "\",";
    json += "\"action\":\"" + rules[i].action + "\"}";
    if (i < ruleCount - 1) json += ",";
  }
  json += "]";
  server.send(200, "application/json", json);
}

void handleAddRule() {
  if (ruleCount < MAX_RULES) {
    rules[ruleCount].id = nextRuleId++;
    rules[ruleCount].type = server.arg("type");
    rules[ruleCount].target = server.arg("target");
    rules[ruleCount].val = server.arg("val");
    rules[ruleCount].action = server.arg("action");
    ruleCount++;
    addLog("New automation rule added.");
    server.send(200, "text/plain", "OK");
  } else {
    server.send(400, "text/plain", "Rule limit reached");
  }
}
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
void loop() {
  server.handleClient();
  handleSequentialLogic();
  handleSafetyTimeouts();
  handleWLEDNightAutomation();
  handleAutomationRulesEngine();
}

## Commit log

2026-08-16 Initial commit: Smart Irrigation System firmware
    ESP32 multi-zone irrigation system with WLED integration, 2FA, and web interface.
2026-08-16 build: add .gitignore for ESP32 and IDE build artifacts
2026-08-16 feat: add release build for Android APK
    - Updated APK binary nameto match firmware web server download endpoint
    - Allows users to download the companion mobile app directly via ESP32 dashboard
2026-08-16 build: initialize assets directory with hardware diagrams, 3D models, and UI media
    - Added project visual assets including UI screenshots and field installation photos
    - Added 3D enclosure CAD models and hardware circuit diagrams
    - Configured media structure for main documentation
2026-08-16 build: initialize assets directory with hardware diagrams, CAD models, and UI media
    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
2026-08-18 feat: add 3D printable STL models and CAD preview assets
    - Added STL files for Banana Pi Pro A20 case, valve enclosures, cable management boxes, and soil sensor casings
    - Added high-resolution CAD preview screenshots to assets directory
    [bananapi-case-bottom-fan.stl, bananapi-case-top.stl, cable-box-cover-large.stl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]
2026-08-18 docs: add hardware wiring diagram for ESP32 and sensors
    - Added Fritzing schematic showing 8-channel relay, 4x soil sensors, DHT11, LDR, MOSFET, and status LED pins
    [hardware-diagram.fzz]
2026-08-18 docs: revamp README as full project showcase and showcase features
    - Redesigned README to highlight system architecture, 8-zone control, and 2FA security
    - Added dedicated section for 3D printable CAD enclosure suite
    - Linked Fritzing schematic assets and pointed setup details to SETUP.md
2026-08-18 docs: add comprehensive SETUP.md guide
    - Create SETUP.md with hardware BOM, pin mapping table, and step-by-step firmware setup
    - Include 2FA configuration, APK editing, and 3D printing deployment instructions
